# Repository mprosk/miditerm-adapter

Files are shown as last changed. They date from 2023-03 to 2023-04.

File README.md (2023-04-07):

# MidiTerm USB Adapter
MIDI UART to USB adapter designed for use with the [`miditerm`](https://github.com/mprosk/miditerm) application.

This is simply the MIDI electrical interface connected to an FTDI UART to USB Serial IC. It allows you to connect to MIDI devices as a USB serial port rather than as a class compliant USB MIDI device, allowing for lower level access to the individual data bytes.

I had a broken Yamaha Model UX16 USB-MIDI Interface cable lying around so I decided to design the board to fit into the enclosure within that cable. It opens easily and has the cables nicely exposed so it was super easy to hack into. Thanks Yamaha

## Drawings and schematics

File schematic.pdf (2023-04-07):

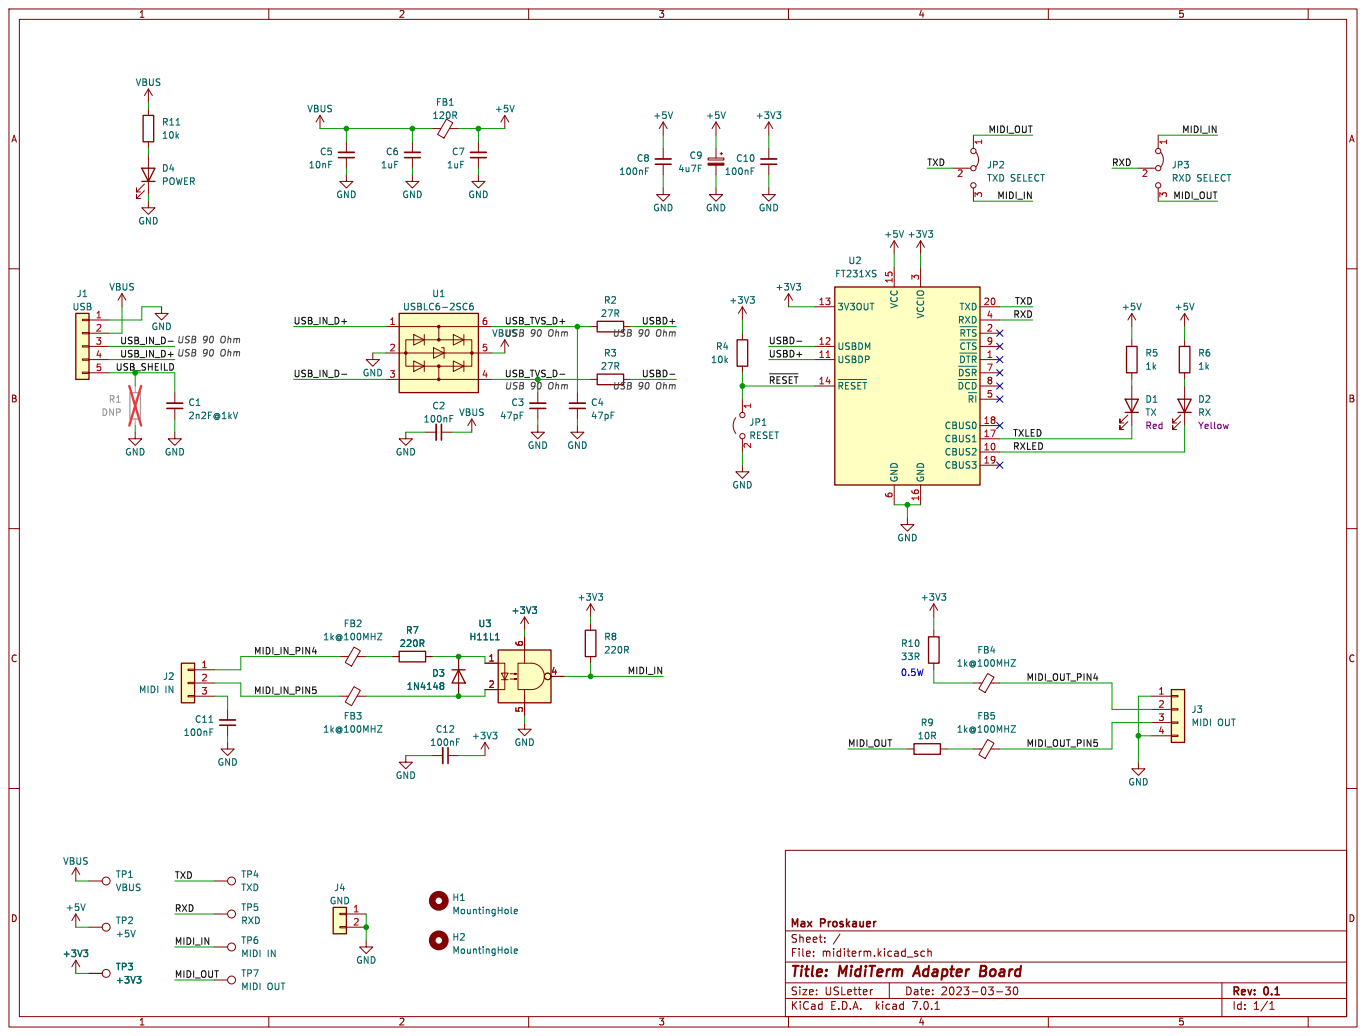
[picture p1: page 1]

~{RESET} USBD- USB 90 Ohm

Id: 1/1 Title: MidiTerm Adapter Board

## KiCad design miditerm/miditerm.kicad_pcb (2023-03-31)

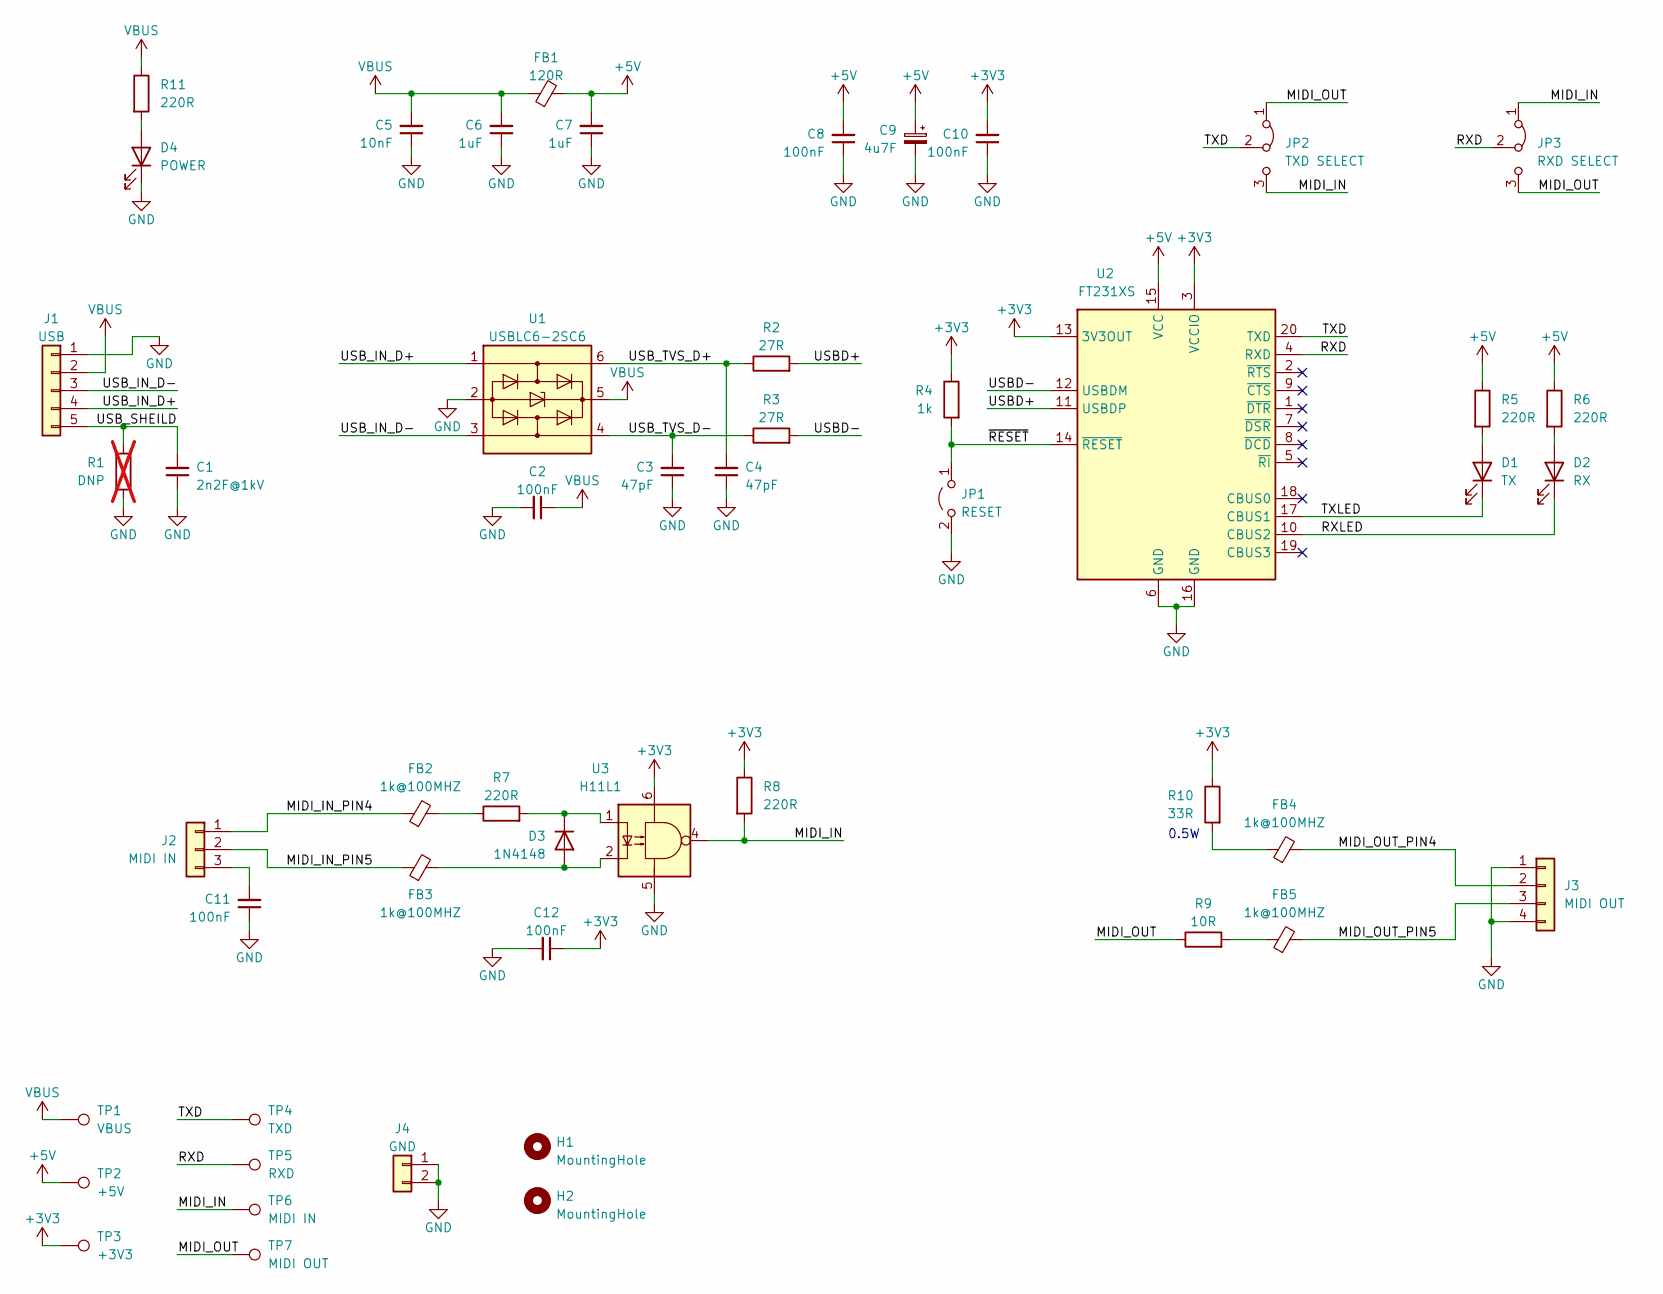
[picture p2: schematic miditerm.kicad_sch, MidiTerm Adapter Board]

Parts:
C1: 2n2F@1kV; C_0805_2012Metric
C2, C8, C10, C11, C12: 100nF; C_0805_2012Metric
C3, C4: 47pF; C_0805_2012Metric
C5: 10nF; C_0805_2012Metric
C6, C7: 1uF; C_0805_2012Metric
C9: 4u7F; CP_Radial_D5.0mm_P2.00mm
D1: TX; LED_D3.0mm
D2: RX; LED_D3.0mm
D3: 1N4148; D_SOD-123
D4: POWER; LED_D3.0mm
FB1: 120R; L_0805_2012Metric
FB2, FB3, FB4, FB5: 1k@100MHZ; L_0805_2012Metric
H1, H2: MountingHole; MountingHole_2.2mm_M2
J1: USB; PinHeader_1x05_P2.00mm_Vertical
J2: MIDI IN; PinHeader_1x03_P2.00mm_Vertical
J3: MIDI OUT; PinHeader_1x04_P2.00mm_Vertical
J4: GND; PinHeader_1x02_P2.54mm_Vertical
JP1: RESET; SolderJumper-2_P1.3mm_Open_Pad1.0x1.5mm
JP2: TXD SELECT; SolderJumper-3_P1.3mm_Bridged12_RoundedPad1.0x1.5mm
JP3: RXD SELECT; SolderJumper-3_P1.3mm_Bridged12_RoundedPad1.0x1.5mm
R1: DNP; R_0805_2012Metric; not fitted
R2, R3: 27R; R_0805_2012Metric
R4: 1k; R_0805_2012Metric
R5, R6, R7, R8, R11: 220R; R_0805_2012Metric
R9: 10R; R_0805_2012Metric
R10: 33R; R_0805_2012Metric
TP1: VBUS; TestPoint_Pad_D1.5mm
TP2: +5V; TestPoint_Pad_D1.5mm
TP3: +3V3; TestPoint_Pad_D1.5mm
TP4: TXD; TestPoint_Pad_D1.5mm
TP5: RXD; TestPoint_Pad_D1.5mm
TP6: MIDI IN; TestPoint_Pad_D1.5mm
TP7: MIDI OUT; TestPoint_Pad_D1.5mm
U1: USBLC6-2SC6; SOT-23-6
U2: FT231XS; SSOP-20_3.9x8.7mm_P0.635mm
U3: H11L1; SMDIP-6_W9.53mm

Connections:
+3V3: C10.2, C12.1, R4.1, R8.1, R10.1, TP3.1, U2.3 (VCCIO), U2.13 (3V3OUT), U3.6
+5V: C7.2, C8.2, C9.1, FB1.2, R5.1, R6.1, TP2.1, U2.15 (VCC)
/MIDI_IN: JP2.3 (B), JP3.1 (A), R8.2, TP6.1, U3.4
/MIDI_IN_PIN4: FB2.1, J2.1
/MIDI_IN_PIN5: FB3.1, J2.2
/MIDI_OUT: JP2.1 (A), JP3.3 (B), R9.1, TP7.1
/MIDI_OUT_PIN4: FB4.2, J3.2
/MIDI_OUT_PIN5: FB5.2, J3.3
/RXD: JP3.2 (C), TP5.1, U2.4 (RXD)
/RXLED: D2.1 (K), U2.10 (CBUS2)
/TXD: JP2.2 (C), TP4.1, U2.20 (TXD)
/TXLED: D1.1 (K), U2.17 (CBUS1)
/USBD+: R2.2, U2.11 (USBDP)
/USBD-: R3.2, U2.12 (USBDM)
/USB_IN_D+: J1.4, U1.1 (I/O1)
/USB_IN_D-: J1.3, U1.3 (I/O2)
/USB_SHEILD: C1.2, J1.5, R1.1
/USB_TVS_D+: C4.2, R2.1, U1.6 (I/O1)
/USB_TVS_D-: C3.2, R3.1, U1.4 (I/O2)
/~RESET: JP1.1 (A), R4.2, U2.14 (~RESET)
GND: C1.1, C2.2, C3.1, C4.1, C5.1, C6.1, C7.1, C8.1, C9.2, C10.1, C11.1, C12.2, D4.1 (K), J1.1, J3.1, J3.4, J4.1, J4.2, JP1.2 (B), R1.2, U1.2 (GND), U2.6 (GND), U2.16 (GND), U3.5
unnamed: D1.2 (A), R5.2
unnamed: D2.2 (A), R6.2
unnamed: D3.2 (A), FB3.2, U3.2
unnamed: D3.1 (K), R7.2, U3.1
unnamed: D4.2 (A), R11.2
unnamed: FB2.2, R7.1
unnamed: FB4.1, R10.2
unnamed: FB5.1, R9.2
unnamed: C11.2, J2.3
VBUS: C2.1, C5.2, C6.2, FB1.1, J1.2, R11.1, TP1.1, U1.5 (VBUS)

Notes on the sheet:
0.5W

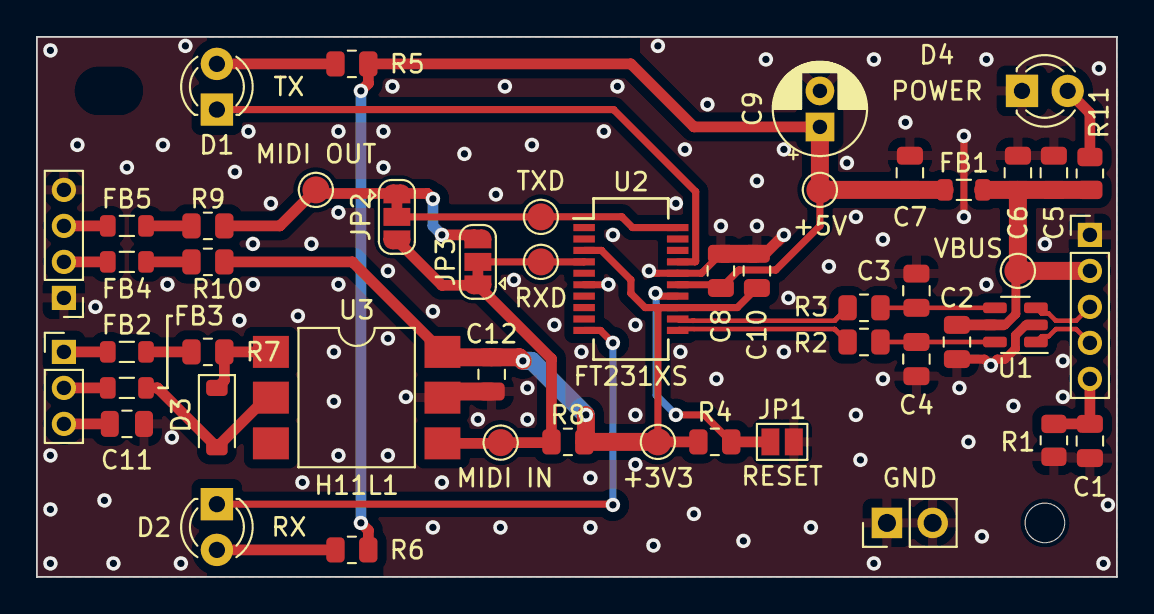
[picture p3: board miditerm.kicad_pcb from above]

Board: 2 copper layers, 60.0 x 30.0 mm, 51 parts (0 on the bottom side), 31 nets.

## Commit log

2023-03-31 Complete PCB design
    [miditerm-B_Cu.gbr, miditerm-B_Mask.gbr, miditerm-B_Silkscreen.gbr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]
2023-04-07 Update resistor values for LEDs
    [miditerm.kicad_sch]
